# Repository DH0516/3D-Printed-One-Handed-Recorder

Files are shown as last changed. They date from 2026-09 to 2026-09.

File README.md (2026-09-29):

# 3D-Printed-One-Handed-Recorder

An open-source, fully acoustic **one-handed soprano recorder** for players who use a single hand (upper-limb differences such as hemiplegia, stroke, cerebral palsy, or congenital limb difference). Home-buildable on a standard desktop FDM 3D printer with no screws and no bought parts: pivot pins and springs are cut from 1.75 mm printer filament, and the body mates with any standard plastic soprano recorder head joint. Chromatic compass C5 to C#7 (26 fingerings) at A = 440.

## Documentation

The [`docs/`](docs/1-index.html) folder is the documentation site, served by GitHub Pages as plain static HTML (`.nojekyll`): project overview, background, printing guidelines, assembly instructions, troubleshooting, and the soprano build guide. Edit the `.md` chapters, then run `python3 docs/render.py` to regenerate the `.html` pages.

## Interactive fingering chart

[`docs/fingering_viewer.html`](docs/fingering_viewer.html) is a standalone, client-side fingering chart with a model selector, showing a simplified instrument diagram per note. It is fully static: the model list comes from `models/manifest.json` and each model's data from its `model.json`, so serve the folder on any static host.

## Models

- **A1**: 4-key system. Key 1 (index finger/octave) sits at the front top with Keys 2 to 4 that lies between the bottom holes. 
- A2: Key 1, the octave key, moves to the back of the body as an actual thumb key. Both Model A variants share the same keys, finger holes, and fingering chart.

## Authors

- Design, CAD, printing, acoustics, and documentations: **Daniel Ha** (Master's researcher in music technology, CAML, McGill University).
- Funding and publication: **Alberto Acquilino**(Western University).

## Contact

For any questions, inquiries, or update requests: [irem25qc@gmail.com](mailto:irem25qc@gmail.com)

## License

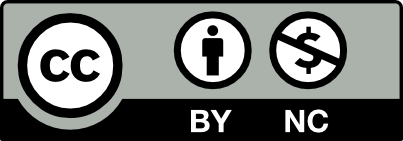
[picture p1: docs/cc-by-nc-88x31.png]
CC BY-NC 4.0


Website content is owned by IREM. The 3D designs (STL files) are released under the Creative Commons Attribution-NonCommercial 4.0 International License ([CC BY-NC 4.0](LICENSE)): free to download, print, modify, and share for personal, academic, and non-commercial use. Resale, commercial manufacture, or commercial reproduction requires prior written permission from IREM.

Generative AI tools assisted with documentation drafting and software scripting; all CAD models, acoustic designs, and physical prototypes were created, verified, and directed by the human authors.

Published 2026-09-27. Last updated 2026-09-27.

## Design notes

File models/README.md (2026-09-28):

# Model data

Each model directory holds `model.json`, the machine-readable backend for the interactive fingering viewer: the complete tonehole map plus the full chromatic fingering chart. These files are generated from the project's CAD model; if a number looks wrong, please open an issue rather than editing the JSON.

`manifest.json` lists the models; the fingering viewer reads it at startup and then loads each model's `model.json`. A recorder with a different key or hole layout needs a `model.json` (with its own `layout` order) plus one manifest entry, and no viewer changes.

## Schema `ohr-model/1`

Top level:

- `id`, `name`, `description`: model identity.
- `layout`: optional. Station ids in top-to-bottom diagram order (a double hole is its base id). This is physical placement only; the fingering chart itself maps each hole id the same way regardless of layout.
- `pitch`: `reference` (tuning standard), `lowest`, `highest`.
- `holes`: one entry per tonehole.
- `fingerings`: one entry per chromatic note.

Hole entry fields:

- `id`: hole name used everywhere in the project (`1` to `6`, `7L`, `7R`, `8L`, `8R`).
- `part`: `body` or `foot` joint.
- `type`: `key` (a printed key closes this hole) or `finger_hole`.
- `key`: which printed key operates the hole, present when `type` is `key`.
- `z`: station of the hole along the bore, millimeters.
- `angle`: bearing of the hole around the bore axis, degrees.
- `diameter`: drilled diameter, millimeters.
- `offset`: lateral shift of the drill axis along the tangent, double holes only.

Fingering entry fields:

- `note`: chromatic note name, `C5` through `C#7`.
- `holes`: map of every hole id to `C` (closed), `O` (open), or `H` (half-hole).

## Units and bearings

All lengths are millimeters. `z` runs from the head-joint tenon end of the body toward the bell. Bearings are taken verbatim from the CAD tables: the finger holes under the operating hand sit at +90, the keyed holes for the missing hand's fingers sit near 0 to -60 at the front, and the back of the instrument is near 180 (the A2 thumb key's hole 1 sits at -103.6).

## Models

- [`A1-2/`](A1-2/): the soprano model in two physical variants, A1 (Key 1 in the key cluster) and A2 (Key 1 at the back as a thumb key). One shared fingering chart.

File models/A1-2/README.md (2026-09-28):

# One-Handed Recorder Soprano A1/2

The soprano model in two physical variants:

- **A1**, the standard variant: Key 1 sits in the key cluster with Keys 2 to 4.
- **A2**: Key 1, the octave key, is moved to the back of the body as a thumb key.

Variant details live in the documentation: [Model Information](https://dh0516.github.io/3D-Printed-One-Handed-Recorder/docs/8-model-information.html) and the [Model A1 page](https://dh0516.github.io/3D-Printed-One-Handed-Recorder/docs/model-A1.html) with its print files.

- `model.json`: tonehole map and the shared fingering chart (10 holes, 26 fingerings, C5 to C#7).

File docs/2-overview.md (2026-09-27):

---
title: Overview
layout: default
---

# 1. Overview

The 3D Printed (FDM) One-Handed Recorder is an open-source project aimed at creating an accessible, fully functional musical instrument. It is inspired by the Dolmetsch one-handed recorder series, which was developed to accommodate musicians with accessibility issues in coordination of their arms, fingers, or hand. It is not a completely hands-free solution, but it provides a starting base for a fully acoustic instrument that can be adapted to fit a player's hands while maintaining playing quality. This is a purely acoustic instrument that does not involve electrical components.

This project focuses on creating a reproducible, open-source design optimized for consumer-grade FDM 3D printing. We utilize standard FDM printing and readily accessible off-the-shelf parts to reproduce the specialized key system required for one-handed play. While the core concepts and design ideas remain the intellectual property of the author/team (distributed under an open-source non-commercial license such as the Creative Commons Attribution-NonCommercial CC BY-NC, which requires that this project is cited when used), users have the freedom to print, modify, and customize the designs for their personal physical needs. Selling the design files or physical instruments for commercial profit is strictly prohibited.

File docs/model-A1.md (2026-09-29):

---
title: Model A1
layout: default
---

# Model A1

Model A1 is the standard variant of the one-handed soprano recorder: Key 1 (the octave key) sits in the key cluster at the front top with Keys 2 to 4, each lying between the lower finger holes. Right-handed by default; mirror all parts along the bore axis for a left-handed instrument.

## Specifications

- Type: Soprano (Descant) recorder in C
- Pitch reference: A = 440
- Keys: 4 printed keys (Key 1 octave key, Keys 2 to 4 tone keys)
- Pin diameter: 2.00 mm bores (pinned with 1.75 mm printer filament, which also forms the key springs)
- Head joint: any standard plastic soprano recorder head joint (not printed)
- Assembly: snap joints, no screws; see [How to Assemble](6-how-to-assemble.md)

## Print Files

Binary STL, meshed at 0.005 mm chordal deviation and 0.1 rad angular tolerance, in print orientation. Printing guidelines are in [How to 3D Print](5-how-to-3d-print.md).

| Part | File | Print height | File size |
| --- | --- | --- | --- |
| Body | [A1-Body.stl](../models/A1/parts/A1-Body.stl) | 171.9 mm | 6.5 MB |
| Foot joint | [A1-Foot.stl](../models/A1/parts/A1-Foot.stl) | 63.6 mm | 7.9 MB |
| Key 1 (octave key) | [A1-Key_1.stl](../models/A1/parts/A1-Key_1.stl) | 10.9 mm | 4.1 MB |
| Key 2 | [A1-Key_2.stl](../models/A1/parts/A1-Key_2.stl) | 25.6 mm | 2.0 MB |
| Key 3 | [A1-Key_3.stl](../models/A1/parts/A1-Key_3.stl) | 17.7 mm | 2.3 MB |
| Key 4 | [A1-Key_4.stl](../models/A1/parts/A1-Key_4.stl) | 26.6 mm | 6.1 MB |

Keys 2 to 4 print as one piece each in this set. The fingering chart shared by both model variants is in the [fingering viewer](fingering_viewer.html).

## 3D Preview

*Be aware that the 3D previewer is purely experimental and cannot accurately render the instrument*

Drag to rotate, scroll to zoom, and pan with right-drag, middle-drag, Shift-drag, or a two-finger touch drag. Loads about 5 MB of mesh data on first click.

<div>
<button id="previewBtnA1" type="button" style="padding:10px 16px;border-radius:8px;border:1px solid #0e6f66;background:#0e6f66;color:#fff;font-weight:600;cursor:pointer;">3D preview viewer</button>
<span id="previewStatusA1" style="margin-left:10px;color:#68747d;"></span>
</div>

<script type="module">
import { mountPreview } from './preview/viewer.mjs';
mountPreview({
  button: document.getElementById('previewBtnA1'),
  status: document.getElementById('previewStatusA1'),
  box: document.getElementById('previewBoxA1'),
  binUrl: 'preview/viewdata.bin?v=6',
  indexUrl: 'preview/viewdata-index.json?v=6',
});
</script>

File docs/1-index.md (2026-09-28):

---
title: One-Handed Recorder
description: 3D-printable one-handed recorder (project overview)
layout: default
permalink: /index.html
---

# 3D Printed (FDM) One-Handed Recorder

Welcome to the documentation for the **3D-Printed-One-Handed-Recorder** project. This documentation is organized into chapters from wide to narrow scope. Click on any section below to view details:

1. **[Overview](2-overview.md)** - Project introduction, goals, and licensing.
2. **[Background & Inspiration](3-background-and-inspiration.md)** - History of one-handed woodwinds, including the tabor pipe, the Dolmetsch legacy, the Flow project, and 3D printing trends.
3. **[Project and Instrument Details and Contexts](4-project-and-instrument-details-and-contexts.md)** - User demographics, instrument details, development realities, and accessibility tenets.
4. **[How to 3D Print](5-how-to-3d-print.md)** - Required tools, filaments/material selection, and safety warning.
5. **[How to Assemble](6-how-to-assemble.md)** - Step-by-step physical assembly guide.
6. **[Troubleshooting](7-troubleshooting.md)** - Common print/assembly issues and acoustic solutions.
7. **[Model Information](8-model-information.md)** - Supported physical recorder variants.
8. **[Reference Tools & Resources](9-reference-tools-and-resources.md)** - Project references, resources, and compliance info.

### Models Available for Download

- **[Model A1](model-A1.md)** (Soprano, A = 440, no thumb key)

---

### Interactive Tools

- **[Interactive Fingering Chart Viewer](fingering_viewer.html)** - Interactive per-note diagrams, staff notation, and a printable one-page chart. Details in [Reference Tools & Resources](9-reference-tools-and-resources.md).

### Contact

For any questions, inquiries, or update requests: [irem25qc@gmail.com](mailto:irem25qc@gmail.com)

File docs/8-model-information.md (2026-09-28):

---
title: Model Information
layout: default
---

# 7. Model Information

The project supports multiple variants of the same one-handed soprano recorder. All variants share one fingering chart (see the [fingering viewer](fingering_viewer.html) and the machine-readable model data in [`models/`](https://github.com/DH0516/3D-Printed-One-Handed-Recorder/tree/main/models)).

- **A1, Soprano**: the standard model, described by the [Model A1 documentation](model-A1.md). The thumb key operates similar to the "A" key, to be pushed with the joint of the index finger, sideways. This particular design involves avoiding the usage of the thumb completely. Right-handed by default; the design is based on a resizing of a historical instrument by J.H. Rottenburgh (originally estimated to be pitched at A = 405 to 415 Hz) to modern pitch (A = 440 Hz). For left-handed play, the design must be flipped horizontally (mirrored along the bore axis). * *Note for organology specialists:* We can likely produce custom model
    designs based on different historical models upon request.
- **A2**: A1 with key 1, the octave key, moved to the back of the body as a thumb key.

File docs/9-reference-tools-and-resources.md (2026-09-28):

---
title: Reference Tools & Resources
layout: default
---

# 8. Reference Tools & Resources

- **[Interactive Fingering Chart Viewer](fingering_viewer.html):** A dedicated web application to view and practice the fingerings, laid out for the one-handed mechanism. The chart itself is the standard baroque chart ("English" and not the "German" system), since the keys change which finger works a hole rather than which holes are open.
  - **Features:** Three note-naming modes (Simple, Solfège, Standard); Simple and Solfège number the instrument's own octaves (`C1` to `C#3`, `Do 1` to `Di 3`), Standard keeps scientific names (`C5` to `C#7`). The playing range is chosen at a reasonable random for people who would require this when learning the instrument as a beginner.
    Staff notes are drawn one octave lower to match the instrument's register. Plus search filtering and print/PDF of the current view.
  - **Standalone Use:** Fully static; it reads the model list and each `model.json` from the `models/` directory, so serve the folder on any static host (GitHub Pages included) and open it from there.
- **[Model A1 Documentation](model-A1.md):** Specifications and print files for the standard soprano build; printing, assembly, and troubleshooting are in chapters 4 to 6.
- **Acoustic Modeling:** Inria Openwind, the open-source wind instrument design toolbox used to calculate and optimize the bore and toneholes.
- **Design Compliance and History:** Historical background on one-handed woodwinds (including expired patents) can be found in [Background & Inspiration](3-background-and-inspiration.md). Open-source licensing and IP compliance details are listed in [Project and Instrument Details and Contexts](4-project-and-instrument-details-and-contexts.md).
- **Community Support:** In these early stages of release, we welcome educators, makers, and families reaching out to us for assembly advice, troubleshooting, and collaborative feedback.

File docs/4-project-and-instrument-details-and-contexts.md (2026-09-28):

---
title: Project and Instrument Details and Contexts
layout: default
---

# 3. Project and Instrument Details and Contexts

### 3.1 Target Audience

- Individuals with accessibility needs of the upper limbs with some limitations (one hand, or two hands with partial limitations).
- Organizations working with such individuals, wanting to provide a starting point for a solution.
- Performers looking for a double-soprano-recorder solution.
- Researchers and educators interested in assistive musical technology.

### 3.2 Instrument Details

- **Type:** Currently only Descant (Soprano) variant. Others will become available if enough users request them.
- **Key System:** Four keys replace the missing hand's fingers and thumb.
- **Fingering:** Requires a specialized fingering chart, which is an inversion of the holes to keys, where keys replace the holes. Left-hand and right-hand models use mirrored variants of the fingering system.
- **Handedness:** The primary instrument design (v1) is right-handed. A left-handed instrument can be made by mirroring everything horizontally along the axis of the bore.

### 3.3 Development Realities

- **Prototyping vs. Mass Production:** For this project, the advantage of 3D printing is rapid prototyping and customizability rather than mass production. General mass production forces standardization which challenges the basic fact that every human is different (not just your handspan).
- **Development Process:** Creating a functional acoustic instrument with 3D printing involves significant calibration, testing, and fine-tuning of acoustic tolerances.
- **Iterative Adjustment:** Print calibration and trial-and-error are expected parts of the process, and designs may need adjustments to fit individual printer tolerances.
- **The Key Challenge:** Mechanical keys have been a major focus in our initial research. Because keys require airtight padding and precise pivots, we collaborated with a professional instrument repairer for direct consultations.
- **Iterative Redesign:** We went through numerous redesign cycles to achieve reliable key seals and responsive movement.
- **Our Goal:** Our goal is to empower users and local makers to fabricate and iterate on these designs themselves using accessible consumer tools.
- **Core Purpose is "Accessibility":** The project is designed to serve upper-limb accessibility, utilizing consumer-grade FDM printers and common, safe FDM thermoplastics.
- **Access and Upgrade Barriers:** While mass-produced plastic soprano recorders are widely available and affordable, upgrading to wooden instruments or obtaining customized parts is costly and difficult. The inherent sophistication of the recorder makes it challenging to customize, particularly due to the complexity of the fipple, but also extending to key layouts and custom sizing.
- **No Proprietary Hardware:** Any non-printed hardware additions (e.g., rubber bands, springs, pads, pins) must be readily purchasable by the general public at standard hardware stores or online retailers. No proprietary or custom-engineered hardware is required. If a specific part is not available, we will suggest alternative items, and users are welcome to contact us for suggestions.
- **Freedom to Print & Modify:** Users are encouraged to print, replicate, test, and modify the files to fit their personal anatomical requirements.
- **Academic Licensing & IP Attribution:** While users have freedom to print and modify the designs, the core design ideas and research development belong to the original author/team, protected under an open-source non-commercial license (such as Creative Commons Attribution-NonCommercial CC BY-NC). This allows anyone to print, share, and modify the designs for personal or educational use, but strictly prohibits commercial sale or exploitation of the design files or finished instruments for money, and requires that the original project and author/team are cited when the design is used or shared.

### 3.4 Materials Selection & UV Resin Safety Hazards

- **We know many materials out there:** When designing a 3D-printable instrument, there are numerous options available, ranging from liquid photopolymers to various meltable thermoplastics.
- **Toxicity of Consumer-Grade UV Resin:** Standard consumer-grade photopolymer UV resins used in stereolithography (SLA/DLP) printers present severe health and safety risks, making them unsuitable for mouth-contact instruments like recorders. In their liquid state, these resins contain reactive monomers, oligomers, and photoinitiators that are known skin and respiratory irritants. Direct contact can cause severe allergic contact dermatitis and chemical sensitization over time (Macdonald et al., 2016; Alifui-Segbaya et al., 2017).
- **Incomplete Curing in Opaque Resins:** If non-translucent (opaque) UV resin is used, it is highly likely that the inside of the printed parts was not cured properly because UV light cannot reach there. Opaque pigments (like Titanium Dioxide or Carbon Black) absorb and scatter UV light, reducing the cure depth (Tomec et al., 2022). This leaves toxic, uncured liquid resin trapped within the internal structures of the instrument, posing severe contact health hazards.
- **FDM with PLA Selection:** Due to these safety concerns, we *had to* choose FDM (Fused Deposition Modeling) with PLA (Polylactic Acid) in the end as our main baseline (though other FDM materials like PETG should work fine too). Unless using certified biocompatible medical/dental-grade resins subjected to strict medical curing procedures, SLA resins must be avoided for mouth-contact instruments.

### 3.5 Design Integrity & Intellectual Property Compliance

To ensure respect for intellectual property while keeping our work completely open-source, the project operates under a set of design integrity and compliance guidelines:

- **Independent Expressive Creation:** All CAD models, photographs, instructions, and text in this repository are created independently by the team.
- **Factual Data Re-derivation:** The fingering layout and acoustic measurements are independently compiled and re-tabulated.
- **Trademark Boundaries:** We market this project under its descriptive name, **3D-Printed-One-Handed-Recorder**. Historical names (such as "Dolmetsch") are referenced purely descriptively and historically to identify the design inspiration, never as a product logo or trademark.
- **Academic Licensing & IP Attribution:** As described in Section 3.3, the project utilizes the Creative Commons Attribution-NonCommercial (CC BY-NC) license. This permits free non-commercial recreation, customization, and study of the design files, provided that the original project and author/team are cited when shared or used.

### 3.6 Fipple Mechanics & Head Joint Exclusion

At this stage, this project does not include design files for printing the head joint (mouthpiece) of the recorder. This decision is based on two primary considerations:

- **Design and Acoustic Complexity:** The fipple and jet mechanisms of the recorder are highly complex and are subjects of popular acoustics studies. In particular, the labium is a very complicated construct, requiring precise sizing of all four sides and the internals. A poorly designed or printed labium causes severe sound defects, commonly observed in low-quality recorders. To avoid providing a low-quality instrument, we recommend using a generic, easily available commercial head joint that plays well.
- **Safety and Liability:** We are hesitant to instruct users to place home-printed objects directly into their mouths. Even if the materials used are certified as safe, the project team cannot assume responsibility or liability for any health concerns that may arise from using home-fabricated mouthpieces.

## References

1. **Photopolymer Biocompatibility & Toxicity:** Macdonald, N. P., et al. (2016). *Assessment of biocompatibility of 3D printed photopolymers*. PLoS ONE, 11(8), e0160741. This study documents the high cytotoxicity of standard 3D printed photopolymers on living cells and warns of leachable toxic compounds.
2. **Dental Resin Toxicity:** Alifui-Segbaya, F., et al. (2017). *Biocompatibility of 3D-printed dental resins*. Dental Materials, 33(11), 1251-1258. Discusses toxic monomer leaching and sensitization risks in oral mucosal contact.
3. **Curing Depth of Pigmented Resins:** Tomec, M., et al. (2022). *Influence of Pigment Concentration on the Cure Depth and Degree of Conversion of Dental Resins*. Journal of Photopolymer Science and Technology, 35(3), 241-248. This study explains how pigments absorb and scatter UV light, exponentially reducing light penetration depth (cure depth) and leaving liquid uncured resin trapped inside the model.
4. **Factual Data & Copyright:** *Feist Publications, Inc. v. Rural Telephone Service Co.*, 499 U.S. 340 (1991). Landmark legal case establishing that factual data and information are not protected by copyright.
5. **Useful Articles Doctrine:** U.S. Copyright Act, 17 U.S.C. §§101, 102(b). Details the exclusion of functional aspects and procedures of useful physical articles from copyright protection.

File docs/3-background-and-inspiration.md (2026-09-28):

---
title: Background & Inspiration
layout: default
---

# 2. Background & Inspiration

Although recorders are unfortunately often misconceptualized as "simple" instruments, they are acoustically sophisticated wind instruments. This misconception largely stems from the mid-20th century, when child music educators (including Zoltán Kodály and others) introduced the recorder into elementary school classrooms as an accessible starter instrument, after being forgotten for a long time after the late Baroque period. In reality, the fipple (jet oscillator) relies on complex nonlinear fluid dynamics to split air and produce sound, requiring high design precision. This historical and modern background highlights the engineering challenges and inspirations behind the development of one-handed woodwinds.

### 2.1 Tracking back on the Fipple: An Early One-Handed Woodwind

Historically, playing a woodwind instrument with a single hand has precedent in the **tabor pipe**, a three-holed fipple flute dating back to the Middle Ages and Renaissance. Designed to be played with only one hand, it allowed the musician to simultaneously play a small drum (the tabor) with their free hand. By using three holes (two on the front, one on the back) and utilizing overblowing techniques to access higher overtones, players could cover a wide playing notes range. This project continues in spirit of these tabor pipes in introducing single-handed fipple woodwind in the performer's arsenal.

### 2.2 The Dolmetsch recorder & Expired Mechanics

Since the 1930s, the Dolmetsch family has crafted custom recorders for individuals with hand accessibility needs.

The Dolmetsch design allows a player to use only one hand (with left- or right-handed variants) by replacing the finger holes of the missing hand with a specialized 4-key mechanism. This system incorporates a two-position thumbkey (closed/open) operated by the little finger of the player's active hand, mapping the notes normally played by the other hand onto keys.

The technical mechanics of the original Dolmetsch recorder-keywork are documented in historical patent records dating from the **1950s**:

| Patent | Subject | Grant Date  |
| --- | --- | --- |
| **GB852164** | Side-mounted closed key operated by the little finger | 8 June 1959 |
| **GB852165** | Bell key | 8 June 1959 |
| **GB852135** | Echo / "piano" key | 1958 |
| **GB666602** | "Tone-projector" | 1950s |

Based on standard term limits, these patents expired in the late 20th century. Public database searches of Espacenet, Google Patents, and the USPTO for any later custom designs (including the ~1997 volume model) did not reveal active patent protection on the basic one-handed key layout. Because all patents covering these historical mechanical keywork designs have expired, reproducing, modifying, or using these mechanics does not violate any patent rights, placing the mechanics in the public domain.

Out of these historical patents, the One-Handed Recorder project only utilizes the side-mounted key operated by the little finger (GB852164). Other wind instruments commonly utilize a pinky key mechanism as well, making the specific novelty of this historical recorder patent unclear; regardless, all of these patents have since expired. The project's first models (A1 and A2) provide a thumb-operated version of the octave key to enable a stronger, more reliable seal of the octave hole, as the pinky-operated key can sometimes be prone to seal leakage. However, an alternative design that maps one-to-one mapping of the keys and also avoiding the thumb usage went back to making this design to be considered again. Without an actual precise knowledge of what this Dolmetsch system is, if this potentially becomes a dispute of "this is my proprietary design", it will be pulled out. Otherwise, all the designs of this project are going to be FREE and OPEN-SOURCED, near FOSS, except commercial reselling of the design for profit, or claiming the intellectual property ownership AFTER this project has become available. The colleagues that are working on this project are actively working to make sure there is a publication to prevent such potential foul play. 

Additionally, the key mechanisms used in this recorder are mechanically no different from the standard keywork used in common Boehm-system woodwinds (such as modern flutes, clarinets, and oboes). They rely on the same fundamental mechanical principles (including pivot hinge tubes, spring returns, and padded cups to seal tone holes) which have been standard, open-domain woodwind engineering concepts for almost two centuries.

### 2.3 The Rise of 3D Printed Musical Instruments

3D printing musical instruments has gained interest in the maker community, supported by resources from organizations like **Prusa Research** (such as their YouTube video ["3D print a Recorder, an Ocarina or a Kazoo"](https://www.youtube.com/watch?v=tMuK4TjFtgI) and accompanying [blog guide](https://blog.prusa3d.com/3d-print-a-recorder-an-ocarina-or-a-kazoo-3d-pritned-musical-instruments_49390/)). These developments highlight how consumer-grade FDM printers can be configured to produce the acoustic geometries of a recorder. To differentiate from closed or proprietary designs, this project provides a free and open-source (FOSS/FOSH), customizable, FDM 3D-printable framework for one-handed recorders.

### 2.4 The "Flow" Project

In recent years, the intersection of music education and assistive technology has led to projects like **Flow**. Developed as an inclusive, low-cost, 3D-printed one-handed recorder, Flow aimed to provide school students with physical disabilities a way to participate in music education. The Flow project demonstrated the application of additive manufacturing to create functional assistive musical instruments.

### 2.5 Historical Prior Art & Other Makers

The concept of one-handed recorders has been independently explored and implemented, reinforcing that the general approach is well-established prior art:

- **Tsukamoto & Fujikoka (1980):** Developed one-handed soprano and alto recorders by adapting Zen-On plastic recorders, documented in the article *"A One-Handed Recorder"* in *Recorder and Music Magazine*.

## References

1. **Tabor Pipe History:** Thoinot Arbeau. (1588). *Orchésographie*. Jean Tabourot's seminal dance manual detailing the history, mechanics, and playing technique of the three-holed tabor pipe.
2. **Dolmetsch Online:** *Gold Series Recorders*. <https://www.dolmetsch.com/goldseriesrecorders.htm>. Details the origins and design of the Dolmetsch 4-key one-handed recorder mechanism.
3. **Prusa Research:** *3D print a Recorder, an Ocarina or a Kazoo*. YouTube Video ([watch](https://www.youtube.com/watch?v=tMuK4TjFtgI)) & Blog Post ([read](https://blog.prusa3d.com/3d-print-a-recorder-an-ocarina-or-a-kazoo-3d-pritned-musical-instruments_49390/)) (2021) demonstrating the viability and considerations of 3D printing functional recorders on consumer FDM printers.
4. **The "Flow" Project:** MDPI. (2021). *Flow: An Inclusive 3D-Printed One-Handed Recorder for Students with Physical Disabilities*. A study on using 3D-printed instruments to promote inclusive music education.
5. **Tsukamoto, T. (1980):** *"A One-Handed Recorder."* *Recorder and Music Magazine*, 5(9).
6. **Dolmetsch Keywork Patents:** C. Dolmetsch. GB852164 & GB852165 (granted 1959), GB852135 (granted 1958), GB666602 (1950s). Historical patent documents retrieved from Espacenet.

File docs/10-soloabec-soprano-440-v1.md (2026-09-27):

---
title: SoloABec Recorders: soloabec-soprano-440-v1 Build Guide
layout: default
---

# SoloABec Recorders - soloabec-soprano-440-v1

Welcome to the build documentation for the **soloabec-soprano-440-v1** model. This instrument design is based on a resizing of a historical instrument by J.H. Rottenburgh (originally estimated to be pitched at A = 405 to 415 Hz) to modern pitch (A = 440 Hz). For organology specialists, we can likely produce custom model designs based on different historical models upon request.

The baseline files for **soloabec-soprano-440-v1** are designed for a right-handed player. To make a left-handed version of the instrument, flip all design files horizontally (mirroring along the bore axis) in your CAD or slicing software.

This guide covers everything you need to 3D print, assemble, and troubleshoot your own one-handed soprano recorder.

## Table of Contents
1. [How to 3D Print](#how-to-3d-print)
   - [What is Needed (Tools & Materials)](#what-is-needed-tools--materials)
   - [Printer Settings](#what-settings-to-use)
2. [How to Assemble](#how-to-assemble)
3. [Troubleshooting](#troubleshooting)

---

## How to 3D Print

### What is Needed (Tools & Materials)

**Materials:**
- **Filament:** High-quality PLA or PETG (e.g., standard 1.75 mm). *Do not use toxic UV photopolymer resins or high-warp materials like ABS/ASA.*
- **Commercial Soprano Head Joint:** Standard 440–442 Hz plastic soprano head joint (such as Yamaha YRS-24B or YRS-302B) with approx. 19.5–20.0 mm tenon socket diameter.
- **Springs / Return Elasticity:** Stainless steel miniature torsion springs (0.3–0.4 mm wire diameter) or orthodontic elastic bands (1/8" or 3/16" medium/heavy pull) for key returns.
- **Sealing Pads:** 1.0 mm – 1.5 mm closed-cell neoprene sheet, natural cork pads, or soft instrument pad leather cut to 9.0–11.0 mm discs matching the key cups.
- **Pivot Pins:** 1.0 mm or 1.2 mm stainless steel rods or brass wire cut to length for the 4 key hinge pivots.
- **Adhesive & Joint Wrap:** Gel cyanoacrylate (super glue) for pads, and cotton/silk thread or PTFE plumber's tape for wrapping tenons.

**Tools:**
- **3D Printer:** Any consumer FDM 3D printer with at least 160 mm Z-height build volume (e.g., Bambu Lab A1 Mini, Prusa MK3/MK4/Mini, Ender 3).
- **Finishing & Deburring:** 400, 800, and 1200 grit wet/dry sandpaper, needle files, and hobby deburring tool.
- **Assembly Tools:** Needle-nose pliers, fine tweezers, flush cutters, and a small hand pin-vise or 1.0/1.2 mm drill bit.

### What Settings to Use
Detailed slicer configuration for optimal acoustic airtightness and mechanical precision:

- **Orientation:** Print body joints vertically on the build plate (tenon facing up or down based on socket bevel).
- **Layer Height:** 0.12 mm (recommended) or 0.16 mm.
- **Wall Loops / Perimeters:** 5–6 wall loops (minimum 2.0 mm total wall thickness) to guarantee full pneumatic seal against air leakage.
- **Infill:** 100% solid infill (or high density rectilinear > 60%) to improve acoustic density and eliminate resonance dampening.
- **Seam Alignment:** Set seam position to "Aligned" or "Rear" placed along the back exterior of the instrument. Do not use random seams or scarf seams inside the bore.
- **Supports:** Disable supports inside tone holes and bore. If needed, support only the external underside of overhang pillars or tenon step lips.
- **Brim:** Outer brim of 8 mm with 0.1 mm brim gap for bed stability during tall vertical printing.

---

## How to Assemble

1. **Preparing the Body:**
   - Check the printed bore for strings, fuzz, or blobs. Smooth internal bore with 800-grit sandpaper rolled around a dowel if necessary.
   - Deburr tone hole edges using needle files so the pads will seat completely flat.
   - Lightly sand the male tenon to remove seam bumps and check initial dry fit into the head joint and foot joint sockets.

2. **Mounting the Keys:**
   - Test each key arm in its pivot pillar. If tight, ream the hinge hole with a 1.0 mm or 1.2 mm drill bit.
   - Slide pivot pins through the pillar posts and key hinges. Secure ends with a tiny dab of glue or mechanical friction.
   - Hook the torsion springs or elastic bands between the key anchors and body hooks, confirming instant, snappy return upon release.

3. **Applying Seals:**
   - Cut pad discs matching key cup diameters (approx. 9–11 mm).
   - Apply a small drop of gel super glue into the key cup and seat the pad firmly.
   - Close the key and check for airtight closure across 360 degrees of the tone hole rim.

4. **Final Fitting:**
   - Wrap the tenon joints with thread or PTFE tape until they slide smoothly into the commercial head joint with a firm, airtight friction fit.
   - Apply a small amount of cork grease or paraffin wax.
   - Play a chromatic scale from Low C up to High D following the fingering chart.

---

## Troubleshooting

- **Issue: Low notes (C, C#, D) sound airy, soft, or fail to speak.**
  - **Solution:** Check key pad seating with a light inside the bore. Re-level pads or file tone hole rims flat. Check tenon joint wrap tightness.
- **Issue: Keys stick or feel sluggish.**
  - **Solution:** Ream key hinge holes slightly with a needle file; ensure pivot pin is straight; increase spring tension.
- **Issue: Tenons bind or won't insert into the head joint.**
  - **Solution:** Reduce thread wrapping passes or wet-sand the tenon diameter with 400-grit sandpaper. Always lubricate with cork grease.

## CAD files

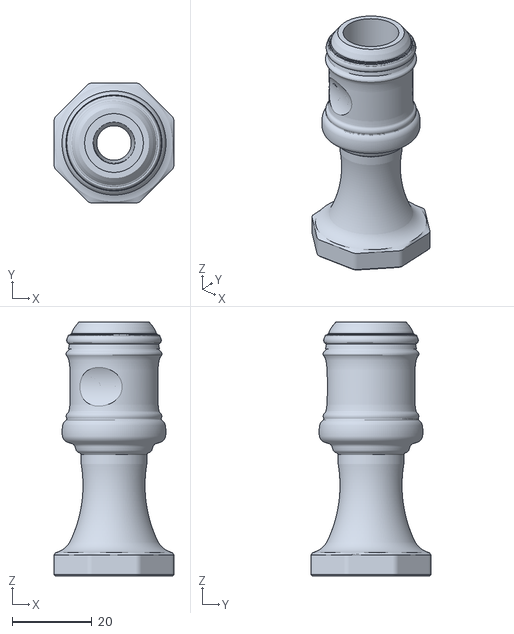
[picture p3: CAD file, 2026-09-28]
models/A1/parts/A1-Foot.stl
30.0 x 30.0 x 63.6

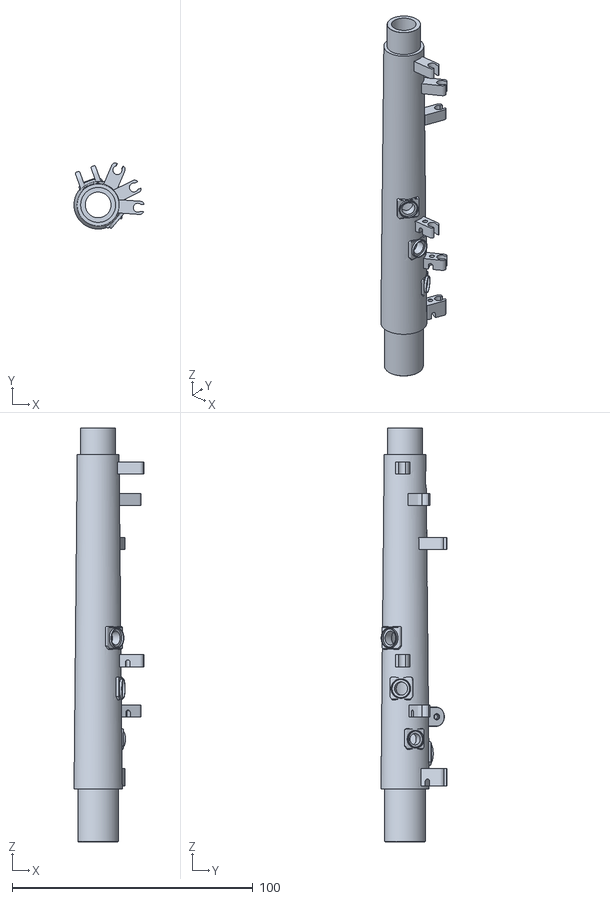
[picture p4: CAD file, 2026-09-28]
models/A1/parts/A1-Body.stl
29.1 x 27.5 x 171.9

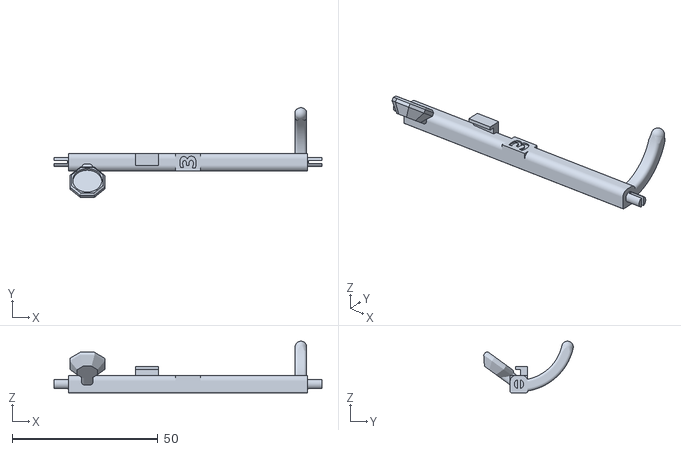
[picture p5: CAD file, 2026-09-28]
models/A1/parts/A1-Key_3.stl
92.1 x 30.8 x 17.7

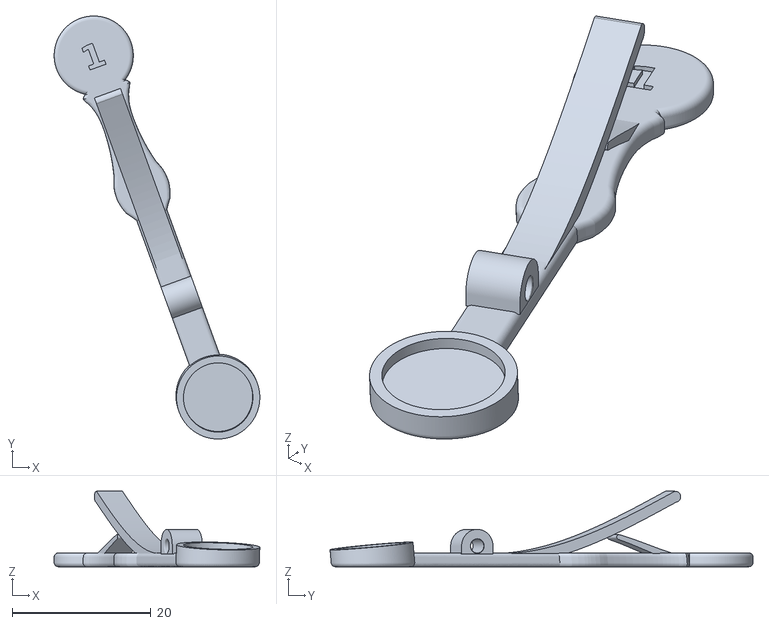
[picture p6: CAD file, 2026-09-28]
models/A1/parts/A1-Key_1.stl
29.6 x 60.9 x 10.9

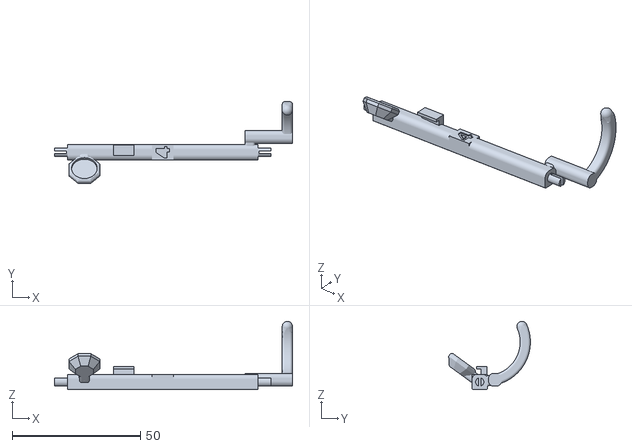
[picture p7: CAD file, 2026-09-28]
models/A1/parts/A1-Key_4.stl
92.7 x 31.8 x 26.6

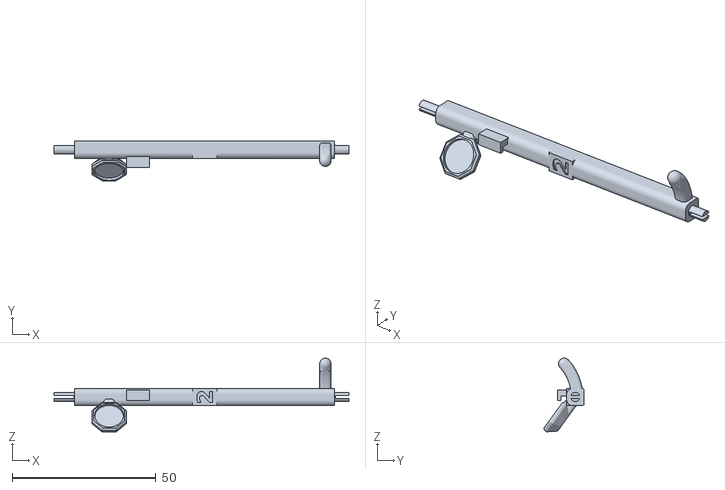
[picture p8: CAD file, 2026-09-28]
models/A1/parts/A1-Key_2.stl
102.5 x 13.9 x 25.6

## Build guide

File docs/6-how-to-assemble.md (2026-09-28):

---
title: How to Assemble
layout: default
---

# 5. How to Assemble

No screws and no bought springs: the keys snap into the pillar slots on the body, and short snippets of 1.75 mm printer filament form the pins and the springs. Tools and materials are listed in [How to 3D Print](5-how-to-3d-print.md).

### Step 1: Clean and Inspect Printed Parts

- Remove all slicer support material from the keys.
- Check the internal bore of the body and foot joint. Clear away any strings, burrs, or loose filament bits so the air column is unobstructed.
- Inspect each tone hole rim. Ensure the rims are clean, flat, and free of burrs; lightly touch them with fine sandpaper if needed so the key pads seat completely flat.
- Lightly sand the male tenons and female sockets with 400-grit sandpaper until parts test-fit smoothly without binding.
- Optionally apply a thin coat of food-grade oil (flax, or similar used in woodwind oiling) to the internal bore for improved sealing.

### Step 2: Prepare and Glue Sealing Pads

- Cut or punch pad discs to the key cup diameter (pad materials are listed in chapter 4).
- Place a small drop of glue in each pad cup, press the pad disc in flat and level, and let the glue cure fully before mounting the keys.

### Step 3: Mount Keys 2 to 4

- Align each key's bracket with the open slots in its pillar pair on the body and press it down until it snaps securely into place.
- Test each key: it should turn smoothly on its pivot without binding or excessive wobble.

### Step 4: Install the Filament Pin Springs (Keys 2 to 4)

- Insert a straight snippet of 1.75 mm filament through the pillar posts and pin holes of each key so that it acts as a pin spring.
- Rotate the filament pin in the direction that applies its appropriate spring force against the shaft's hook.
- Snap off the filament at the notch so the pin spring stays in one rotational position.
- Press each touchpiece with your finger: the pad should lift smoothly, and when you release, the pin spring should snap the pad shut instantly over the tone hole rim.

### Step 5: Mount Key 1 (Octave Lever)

- Position Key 1 into its pin slot on the body. The sheet spring is already 3D printed with it.
- Cut a straight snippet of 1.75 mm filament to the width of the pin slot and slide it through the pin slot holes and Key 1, creating a clean pivot pin. Trim any excess spring.
- Key 1's return spring is the flexible printed sheet spring, printed as part of the key itself; it keeps the octave hole closed at rest until the touchpiece is pressed.

### Step 6: Fit the Joints

- Wrap both tenons of the body with paper tape, thread, an O-ring, or cork (all work fine) until the head joint and the foot joint each slide on with a firm, airtight friction fit. A light touch of cork grease helps.
- Push on the head joint and the foot joint, and visually align the front tone holes with the labium window on the head joint so the instrument is straight.

### Step 7: Perform Airtightness and Playability Checks

- Gently blow warm air through the recorder while keeping all tone holes closed.
- Listen and feel for air leaks around the pad cups. If a pad is not sealing completely, check that the pad sits flat in its cup and that the pin spring provides enough closing force.
- Test finger action: press each touchpiece to ensure full, unobstructed travel and snappy spring return.
- Play through the notes of the fingering chart.

### Customizations

If you need pre-cut tenon grooves for thread or O-ring seals, or you modified the design and want to share it, write to the contact address on the [main page](1-index.md).

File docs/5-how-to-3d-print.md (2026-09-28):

---
title: How to 3D Print
layout: default
---

# 4. How to 3D Print

### 4.1 What is Needed (Tools & Materials)

**Materials:**

- **Filament:** Standard 1.75 mm PLA or PETG. Warping materials like ABS and ASA have not been tested at all, and we never recommend using photopolymer resin, especially for any mouth-contact part; see [Project and Instrument Details and Contexts](4-project-and-instrument-details-and-contexts.md).
- **Commercial Recorder Head Joint:** A standard 440-442 Hz plastic soprano recorder head joint is required for the **soprano-440** model, as the head joint is not printed in this project. (See [Fipple Mechanics & Head Joint Exclusion](4-project-and-instrument-details-and-contexts.md#36-fipple-mechanics--head-joint-exclusion) for details).
- **1.75 mm Filament Snippets:** A few short pieces of ordinary printer filament. One acts as the pivot pin for Key 1; the others are the bending pin springs that close Keys 2 to 4.
- **Sealing Pads:** Discs of 1.0-1.5 mm closed-cell neoprene, natural cork, craft foam, or soft leather, cut to the key cup diameters. This is the only part of the instrument where it cannot be "3D printed".

- **Tenon Seal:** Paper tape, thread, O-ring, or cork for the friction joints.

**Tools:**

- **3D Printer:** Any consumer FDM printer with at least 160 mm of Z height. The middle joint is the tallest part at roughly 15 to 16 cm.
- **Finishing Tools:** 400 to 1200 grit wet/dry sandpaper, miniature needle files, and deburring tools to clean up tone holes and clear away print stringing hair if you experience stringing issues.
- **Pliers & Tweezers:** Needle-nose pliers, fine tweezers, flush cutters, or a small craft knife.

### 4.2 What Settings to Use (Suggested Recommendations)

> [!NOTE]
> Most generic or general slicing settings should be okay for a standard print. The fine settings detailed below are recommended from a troubleshooting perspective to optimize print quality, airtightness, and acoustic performance.

- **Calibration & Tolerances:** Ensure your printer is properly calibrated for dimensional precision before printing. The instrument design is optimized so that standard tolerances of ~0.5 mm are generally okay.
- **Orientation:** Print the body and foot joint vertically along the bore axis with the tenon on the build plate. Never print the acoustic body horizontally: horizontal layer lines cause bore distortion and air leakage. Print the keys with standard slicer supports.
- **Layer Height:** 0.12 mm is recommended for better acoustic seal and detail on tone hole bevels; 0.16 mm is acceptable.
- **Wall Perimeters:** Use at least 4 to 6 wall loops (minimum 2.0 mm total wall thickness) to ensure complete airtightness through layer lines and provide structural rigidity.
- **Infill:** Printing as a full solid (100% infill) is ideal, but if you are experiencing over extrusion issues, you could print with sparse infill, while keeping the infill density high (80%+). The sparse infill pattern itself does not affect the sound; choose a simple pattern (such as grid or rectilinear) to save print time and ensure complete sealing around the bore.
- **Bridges:** Disable "thick internal bridges" and "detect overhang walls" in your slicer settings to prevent internal bore distortions. (Unless you have a specific way to handle these).
- **Supports:** Try to not add supports on the tone holes, as supported holes can come out dirtier and rougher than expected. Supports are needed for the keys, tenons, and key holders. I prefer tree supports for easier detachment.
- **Seams:** Random seams provide stronger seals for the bore. Avoid using scarf seams as they can introduce leaks.
- **Brim:** Use an outer brim of at least 5 mm to ensure solid bed adhesion when printing tall joint sections vertically.

### 4.3 Pitch Precision & Tone Hole Resizing

Because 3D printing involves material shrinkage, and slicing variations, the printed instrument's acoustic pitches might not be perfectly precise out of the box. 

Generally speaking, adjusting the tone holes are not advised. You can consider cleaning the holes and the bore if the print produced stringings, but further changes are not necessary. There are compensatory shapes around tone holes to offset the overhang sagging. Please consider reprinting after checking your calibrations and measurements rather than jumping to making manual changes on the printed instrument.

## References

1. **Related Acoustic Research:** Ha, D. and Scavone, G. (2026). "Acoustic Impedance and Viscothermal Losses in FDM-Printed Cylindrical Waveguides: Influence of Surface Conditions and Infill Structures." *Proceedings of Meetings on Acoustics*, International Symposium on Musical Acoustics (ISMA 2026), Helsinki, Finland, 15-17 June 2026. DOI: TBD.

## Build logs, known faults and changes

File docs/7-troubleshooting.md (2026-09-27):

---
title: Troubleshooting
layout: default
---

# 6. Troubleshooting

### 6.1 Sound & Acoustic Issues

- **Issue: The recorder sounds "airy", weak, or fails to speak on low notes (Low C, C#, D).**
  
  - **Cause 1: Inadequate Key Pad Seal.** Inspect each key pad using a flashlight placed inside the bore in a darkened room or test with a narrow paper feeler gauge. If light leaks around the pad rim, re-seat or sand the tone hole chimney flat.
  - **Cause 2: Tenon Joint Leakage.** Air escaping at the head-to-body or body-to-foot joint weakens acoustic pressure. Add extra layers of thread, PTFE tape, or cork wrapping to achieve an airtight seal.
  - **Cause 3: Leaky Print Walls.** If improperly printed, air can bleed through micro-gaps between layer lines, usually happens around toneholes. Ensure at least 4 perimeter walls were used, or seal the interior bore with a thin coat of mineral oil or paraffin wax. Sparse Infill patterns likely will not change the acoustic outcome.

- **Issue: Lower register sounds weak compared to upper, or constantly overblows.**
  
  - **Cause 1: Octave Thumb Hole or Key Leak.** The thumb hole key (Key 1) or other keyed hole must seal completely when fully closed and provide a clean aperture when vented.
  - **Cause 2: Leaky Print Walls.**

### 6.2 Mechanical & Keywork Issues

- **Issue: Keys stick, bind, or are sluggish to return.**

  - **Cause 1: Pivot Friction.** The pivot hole in the key hinge may be too tight. Gently sand or ream the hole until the key turns freely.
  - **Cause 2: Insufficient Spring Tension.** Increase the bending preload on the filament pin spring, or replace the snippet with a fresh one.
  - **Cause 3: Key Arm Clearance.** Check that key arms do not rub against adjacent pillar posts or the outer curvature of the body.

- **Issue: Key pads fall off or shift out of alignment.**
  
  - **Solution:** Clean the key cup thoroughly with isopropyl alcohol before gluing. Use gel cyanoacrylate or contact cement, ensuring full surface contact and allowing adequate cure time under clamping pressure.

### 6.3 Joint Fit & Physical Tolerances

- **Issue: Joints are too tight to assemble or bind during insertion.**
  
  - **Solution:** Do not force printed joints together. Apply less thread/cork wrapping. If the bare printed tenon is oversized, wet-sand the outer diameter with 400-grit sandpaper until it inserts smoothly. Then apply cork grease or wax.

- **Issue: Joints are loose or wobble during play.**
  
  - **Solution:** Add more tenon wrap until the connection is snug, rigid, and airtight.

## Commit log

2026-09-27 bootstrap: docs series, fingering viewer, per-model JSON backend, CC BY-NC 4.0 license
    [fingering_soprano.csv]
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2026-09-27 dedupe docs: one source per topic, steel-hardware BOM hallucinations removed
    - COMPREHENSIVE_GUIDE deleted; its correct content (filament BOM, full
    assembly steps) migrated into chapters 4 and 5, its duplications dropped
    - chapter 10 cut to model-specific facts + links (was a restatement of 4-6)
    - chapter 4 BOM: filament pins/springs replace torsion springs and 1.0/1.2
    mm steel pins; Yamaha YRS examples and 160mm Z-height kept
    - chapter 5 assembly: full 8-step sequence, mermaid block dropped
    (renders as raw code on GitHub Pages)
    - chapter 6: torsion-spring cause rewritten to filament pin spring
    - 1-index/9: viewer blurb stated once, community + Openwind moved to 9
2026-09-27 remove brand references: head joint spec is any standard plastic soprano head
2026-09-27 fingering viewer: JSON backend (model.json) replaces CSV
    - viewer fetches models/<id>/model.json via a model selector; holes,
    key/finger-hole styling, and L/R pairing derive from the JSON, so
    models with different key or hole configurations need no viewer change
    - Open Local button now loads a model.json
    - staff notation octave bug fixed: scientific names (C5..C#7) previously
    all rendered in octave 4 because the digit was ignored
    - fingering_soprano.csv removed from docs (authoring CSV stays in the
    private repo as the generator input)
    - verified with a stubbed-DOM run: A1 default load renders 8 stations,
    all 10 holes closed on C5, 26 note cards; A2 switch loads
    [fingering_soprano.csv]
2026-09-28 viewer: simplified instrument diagram, no repo or geometry references
    - diagram is a schematic recorder silhouette: head joint with window,
    body, flared foot; Key 1 to 4 touchpieces above finger holes 5 to 8,
    evenly spaced in model order, uniform sizes, L/R doubles side by side
    - closed/half/open fills on both keys and holes; labels beside stations
    - UI text no longer names files or paths (Open Local Model File, model
    name only in the sidebar)
    - model descriptions drop engineering vocabulary
    - verified via stubbed-DOM run: 4 touchpieces, 6 circles, C5 all
    closed, C#7 half-filled Key 1
2026-09-28 viewer: static embedded model data + physical key layout in diagram
    - model.json gains layout: station order down the instrument
    (Key 1, Hole 5, Key 2, Hole 6, Key 3, Hole 7, Key 4, Hole 8);
    placement only, fingerings still map by hole id
    - model data embedded in the page between generated markers; the
    generator rewrites the block, viewer reads embedded data first and
    needs no fetch (fetch stays as fallback for models without embeds)
    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
2026-09-28 viewer embed: minimal projection only (ids, types, keys, layout, fingerings)
    The embedded model data carries no geometry fields; the viewer renders
    purely from station order and fingering states. model.json files keep
    the full documented dataset. Generator picked up the edited spec angles
    (holes 2/3/4 at 25/-10/-40, finger holes at 110) into model.json.
2026-09-28 viewer: finger holes labeled 1 to 4 (display only)
    Hole N of the project's 5 to 8 shows as N minus 4, pairs keep their
    L/R suffix (Hole 3L, Hole 4R). Data ids, layout, and fingerings are
    untouched.
2026-09-28 viewer: Keys 2 to 4 draw inverted (closed as open, open as closed)
    Cosmetic only, diagram fills; Key 1 and all finger holes keep the
    normal mapping, the table still reports the true chart states, and the
    fingering data is untouched.
2026-09-28 viewer: Key 1 draws inverted too; half renders as closed
    All four keys: closed draws open, open and half draw closed. Finger
    holes unchanged; chart data and state table untouched.
2026-09-28 merge A1 and A2 into one model entry A1/2; Key 1 icon round
    - variants A1 and A2 share keys, holes, and fingerings, so one chart
    entity: models/A1-2/model.json, viewer selector shows Soprano A1/2
    - Key 1 station draws as a circle; Keys 2 to 4 stay touchpiece bars
    - generator emits the single model and its minimal viewer embed
2026-09-28 viewer redesign (second agent pass) adopted
    Visual overhaul: warm palette, serif headings, dark sidebar rail,
    focus states, tighter diagram marks. New Simple note naming (relative
    octaves, C5 reads C1, staff drawn an octave lower to match); Standard
    and Solfège kept. All-Fingerings card grid and full-chart print export
    removed; print now outputs the current view. Chapter 9 feature list
    updated to match. All functional behavior verified: layout order,
    round Key 1, key color inversion, hole relabel, embedded A1/2 model,
    26-note list, state table.
2026-09-28 viewer: draggable sidebar width
    Divider between sidebar and main: pointer drag or arrow keys (16 px
    steps), clamped 240 to 520 px, persisted in localStorage. Hidden in
    print. Clamp logic and full rendering regression verified.
2026-09-28 viewer: Solfège relative octaves, staff one octave lower, naming order, drop local-file button
    - Solfège numbers the instrument's octaves like Simple (Do 1, not Do 5)
    - every staff note now draws one octave lower in all modes, not just
    Simple; C5 sits at the C4 staff position
    - Note Naming order: Simple, Solfège, Standard
    - Open Local Model File button and hidden file input removed; the page
    is fully embedded, chapter 9 updated
2026-09-28 viewer: print/PDF outputs the full fingering sheet
    Print shows every fingering on one page in a 9-column grid; each cell
    is the instrument diagram, the note name, and the staff drawing, in
    that order. Labels follow the active naming mode (Simple default:
    C1 to C#3). State table and single-note view are not printed. Sheet
    rebuilds on model load and naming change.
2026-09-28 print sheet: no station labels per cell, no pitch reference
    Cell is diagram, note name, staff. Station text (Key/Hole) only on
    the screen diagram. The embedded model projection drops the unused
    pitch field so the viewer file carries no pitch reference at all.
2026-09-28 viewer code audit: model JSON out of the HTML, manifest-driven
    - embedded model data block removed; viewer fetches
    models/manifest.json then models/<id>/model.json (any static host)
    - hardcoded model list replaced by the manifest; a future recorder
    with a different key or hole layout needs only a model.json with its
    own layout order plus one manifest entry, no viewer changes
    - dead CSS var removed, stale embed branch and duplicate selector
    wiring deleted; single init() entry point
    - generator writes the manifest instead of rewriting the HTML
2026-09-28 docs: render plain static HTML, drop Jekyll
    - docs/render.py converts every chapter .md to .html with a shared
    header linking the docs index and the fingering viewer; chapter links
    rewritten from .md to .html; committed .html served as-is
    (.nojekyll), _config.yml removed
    - landing page links the fingering viewer directly
2026-09-28 docs: previous/next pager between chapter pages
    Numeric chapter ordering (10 after 9), pager at the bottom of every
    page with titles; landing page gets only Next, last chapter only
    Previous. Single-file build keeps internal anchors.
2026-09-28 Model A1 documentation page with STL print files
    docs/model-A1.md: specs (Soprano in C, A=440, 2.00 mm pin bores) and
    the six print files (Body, Foot, Keys 1-4) as binary STL meshed at
    0.01 mm chordal deviation from the STEP set; linked from the docs
    landing page, included in the pager chain and single-file build.
    Volumes: body 26580.16, foot 18169.34, K1 1076.54, K2 3715.47,
    K3 3621.56, K4 3839.29 mm3.
    [Body.stl, Foot.stl, Key_1.stl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]
2026-09-28 model A1 page: print height + file size replace triangles/volume; drop compass claim and v0.1 designation
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2026-09-28 assembly chapter rewritten: dedup and de-hallucination
    - pad materials point at chapter 4 instead of restating the BOM
    - duplicated filament-insertion sentences merged into one step 4
    - duplicated foot/head joint wrap steps merged into one joint-fitting
    step
    - broken 'craft adhesive' bullet restored to a real sentence
    - speculative tenon-groove roadmap replaced by a pointer to the
    contact address; chromatic-scale phrasing dropped
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2026-09-28 3D preview: hole-free decimation and correct camera framing
    - decimation was dropping every k-th triangle, shredding surfaces into
    holes; replaced with vertex clustering on a 0.35 mm grid: closed
    surfaces survive, 80k triangles, 2.8 MB (was 135k / 4.7 MB)
    - camera fit now derives from the world-space bounding box instead of
    hand-mapped axes, which had the model as a small off blob; verified
    in a real browser: canvas-filling render with body, arms, cups
2026-09-28 3D preview: scene logic extracted and smoke-tested in Node
    The pure scene build (meshes from the binary, camera fit) now lives in
    preview/scene.mjs, shared by the page and by preview/test_scene.mjs,
    which builds the real 80,807-triangle scene in Node and fails loudly
    on missing parts, size mismatch, non-finite coordinates, or an
    implausible camera distance. Page module imports it; no duplicated
    geometry code. package.json marks the folder as ESM.
2026-09-28 STLs regenerated at 0.005 mm / 0.1 rad: scar-free fine mesh
    The first export used OCCT's legacy single-argument meshing, whose
    hidden default angular tolerance (0.5 rad) left faceting scars on
    small curves. step2stl now meshes through IMeshTools_Parameters with
    an explicit 0.1 rad angle and 0.005 mm deflection: Key 1 85,618 tris,
    Body 135,521, Foot 165,112. Heights unchanged; file sizes updated.
    [Body.stl, Foot.stl, Key_1.stl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]
2026-09-28 Model A2 page and print files; A1 table reformatted (dh)
    Body and Key 1 for the thumb-key variant as fine-mesh STL (129,051
    and 80,808 triangles); foot and Keys 2 to 4 are shared with A1 and the
    page links there instead of duplicating files. Landing page lists both
    models.
    [Body.stl, Key_1.stl]
2026-09-28 A2: complete part set (foot and Keys 2 to 4 included)
    [Foot.stl, Key_2.stl, Key_3.stl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]
2026-09-28 STLs renamed with model prefix (A1-Body.stl, A2-Key_1.stl, ...); page links follow
    [A1-Body.stl, A1-Foot.stl, A1-Key_1.stl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]
2026-09-28 3D preview for Model A2; viewer refactored to a shared module
    A2 data derives from the assembled dump by rotating the key-1 group
    by the documented design delta (-213.6 deg about the bore; verified
    numerically: cup bearing delta 146.7 vs 146.4 deg expected). The
    click-to-load viewer now lives in preview/viewer.mjs; both model pages
    mount it with unique element ids, so the single-file build carries
    both previews without collisions.
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2026-09-28 pull Model A2 from the site pending release
    Removes the A2 page, its STL set, and its 3D preview data; the A1
    page, files, and preview stay. A2 material remains in git history for
    restore when release is approved.
    [A2-Body.stl, A2-Foot.stl, A2-Key_1.stl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]
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2026-09-29 Preview data now dumped by the C++ stages from live CAD geometry
    stage12 (A1) and stage14 (A2) tessellate the assembled design-frame
    parts, flip to the standing world frame, decimate, and write the
    viewdata bins directly; the A2 preview shows the current tube and the
    rotated key-1 group instead of the September 24 snapshot. Pages fetch
    v=4.
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
